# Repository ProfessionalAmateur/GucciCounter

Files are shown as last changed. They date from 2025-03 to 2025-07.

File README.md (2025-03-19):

# Gucci Counter

## Parts to buy:
1. **TinyScreen+** (https://tinycircuits.com/products/tinyscreenplus)
2. **TinyAccelerometer** (https://tinycircuits.com/products/accelerometer-tinyshield)
3. **Battery** (https://tinycircuits.com/products/lithium-ion-polymer-battery-3-7v-290mah)
4. **M3 bolt** (35mm)
5. **M3 Locking Nylon Nut**  
6. **Tactical paper clip** To press the buttons on the screen

## Parts to 3D print:  

1. **Main housing** https://github.com/ProfessionalAmateur/GucciCounter/blob/master/TinyScreenMainHousingPicatinny.stl  
2. **Picatinny small arm:** https://github.com/ProfessionalAmateur/GucciCounter/blob/master/MainHousingArmPicatinny.stl  
3. **Back Cover:** https://github.com/ProfessionalAmateur/GucciCounter/blob/master/TinyScreenBackPlate.stl  
(Please rotate objects as needed with your slicer for best printing quality)  

Once printed I drill out the bolt holes because the original design wanted something smaller, but I think an M3 bolt is better/best for a picatinny rail.

**Code to download:**  
https://github.com/ProfessionalAmateur/GucciCounter

**Assembly:** The accelerometer clips right into the back of the TinyScreen+ as well as the battery.
Once assembled insert the screen, accelerometer and battery into the 3d printed housing and affix the back cover.  
  
Connect the screen to your computer via a micro USB cable (this cable also charges the battery).
Open up Arduino IDE and upload the code program downloaded in step 3. (You may need to research how to connect your arduino to your PC but it is really straight forward.)

After the battery is fully charged and program uploaded to the device attached the unit to the picatinny rail if your desire.

## Button functions:

**Top Left:** Resets to 30 round magazine and will decrement with each round.  
**Top Right:** : Resets to 20 round magazine and will decrement with each round.  
**Bottom Left:** Resets to 0 and will increment with each round.  
**Bottom Right:** Resets to 0 and will increment with each round.  

## Constants/Variables
There are a couple of constant variables in the program you can feel free to change:  
  
**BIG_MAG:** I keep mine at 30 but if folks have 50 or 100 or 256 round magazine you will want to change this number.

**LITTLE_MAG:** Same as above if you have  10, 5 or 1 round magazine you will want to change this number.   

**Z_AXIS_GFORCE_THRESHOLD:** This value is a little tricky.  For my AR (which has almost no recoild because I built it myself and did it perfectly) a shot is just over 2g's but every gun is different, so if a shot is not registering I would lower this number.  If its registering too many, for some reason, raise it up.  This is where all the research and development dollars go into tuning.  

**X_AXIS_GFORCE_THRESHOLD & Y_AXIS_GFORCE_THRESHOLD:** These settings are to help prevent accidental 'round counts' when the firearm is placed down (On the stock or barrel) and registers an high G force across two or three directions.  All shots will come from the z-axis, but if you place your gun down or drop it in a corner it might register acceleration across all 3 axis'.  There is probably a better way to do this but alas, this is how I did it.

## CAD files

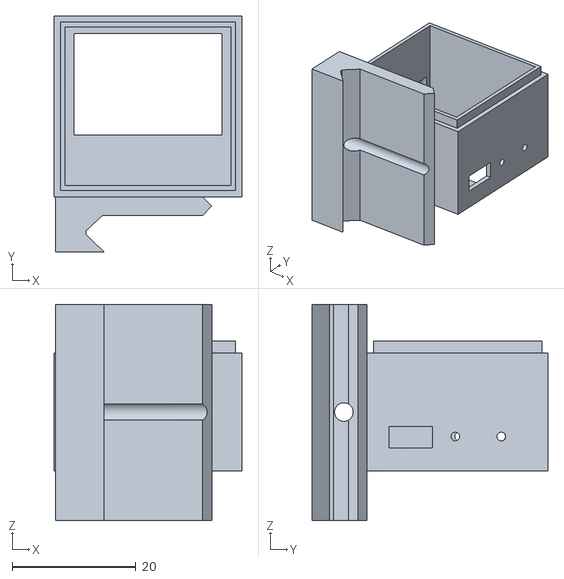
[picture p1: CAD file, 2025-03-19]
TinyScreenMainHousingPicatinny.stl
30.4 x 38.2 x 35.0

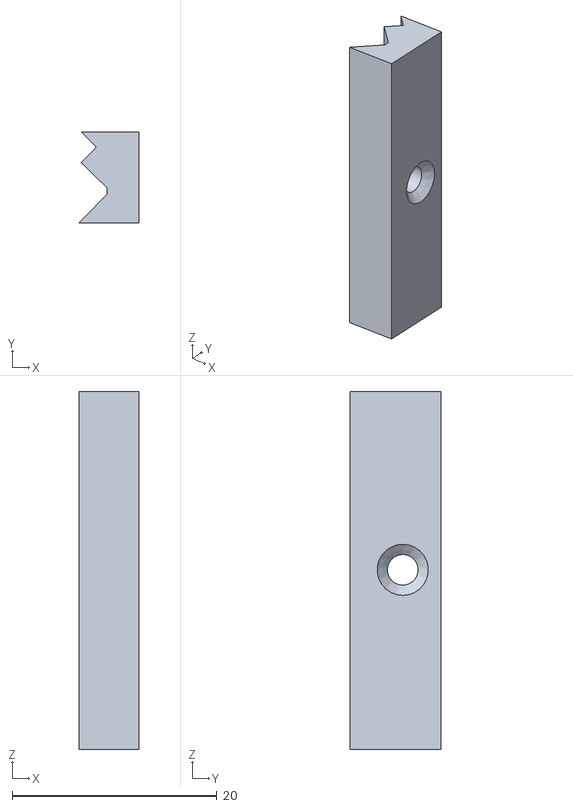
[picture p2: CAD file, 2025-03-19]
MainHousingArmPicatinny.stl
5.88 x 8.91 x 35.0

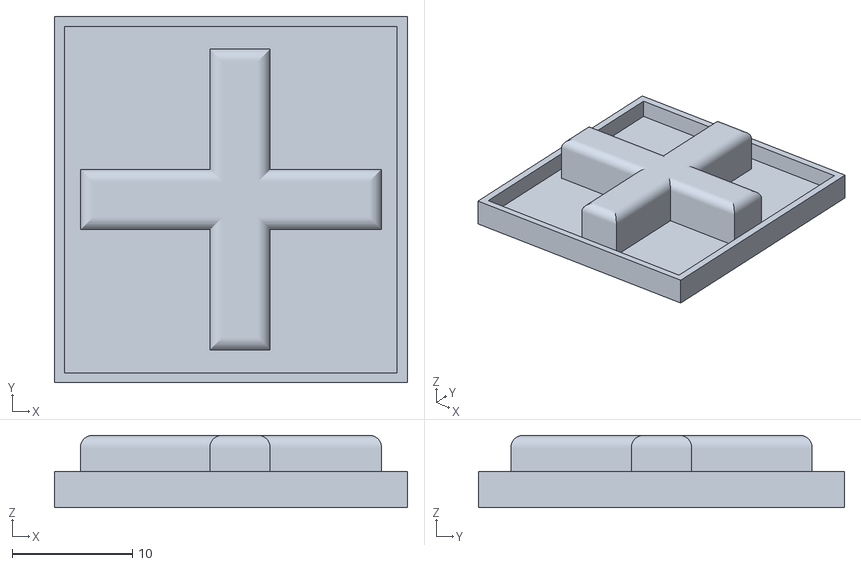
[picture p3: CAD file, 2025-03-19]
TinyScreenBackPlate.stl
29.3 x 30.4 x 6.00

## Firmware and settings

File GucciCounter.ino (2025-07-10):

#include <Wire.h>
#include <SPI.h>
#include <TinyScreen.h>
#include "BMA250.h"
#include <cmath>

// Library must be passed the board type
// TinyScreenPlus for TinyScreen+
TinyScreen display = TinyScreen(TinyScreenPlus);
int ctr = 0;
BMA250 accel_sensor;
int16_t x, y, z;
float max_xg = 0;
float max_yg = 0;
float max_zg = 0;
bool increment = true;
const int BIG_MAG = 30;
const int LITTLE_MAG = 20;
const float Z_AXIS_GFORCE_THRESHOLD = 0.50; // This is pretty low, but when the last round is fired and the bolt locks back the counter wasnt not registering.
const float X_AXIS_GFORCE_THRESHOLD = 0.93;
const float Y_AXIS_GFORCE_THRESHOLD = 0.75;

// I need to play with this number as for some shots met all the requirements but did not register.
const int COUNT_DELAY = 50;

// Define the update interval (in milliseconds)
#define UPDATE_INTERVAL 16 // 500 ms = 0.5 seconds

void setup(void)
{
  display.begin();
  // Sets main current level, valid levels are 0-15
  display.setBrightness(15);
  flipDisplay(true);
  Wire.begin();
  // Set up the BMA250 acccelerometer sensor
  accel_sensor.begin(BMA250_range_16g, BMA250_update_time_16ms);
}

void loop()
{
  // If the BMA250 is not found, nor connected correctly, these values will be produced
  // by the sensor
  if (x == -1 && y == -1 && z == -1)
  {
    // Print error message to Serial Monitor
    // Should probably error some how, some way....
  }
  else
  { // if we have correct sensor readings:
    writeAccel();
  }
  buttonLoop();
  // delay(UPDATE_INTERVAL);
}

void flipDisplay(bool flipFlag)
{
  display.setFlip(flipFlag);
}

void writeAccel()
{
  if (!increment && ctr == 0)
  {
    writeGameOver();
    return;
  }

  display.clearScreen();
  display.drawRect(0, 0, 96, 64, TSRectangleNoFill, 255, 0, 0);

  // Fetch accelerometer data and convert as needed.
  accel_sensor.read();
  float scaleFactor = 32.0;
  x = accel_sensor.X;
  y = accel_sensor.Y;
  z = accel_sensor.Z;
  // Optionally, convert to m/s²
  float x_g = (x / scaleFactor);
  float y_g = (y / scaleFactor);
  float z_g = (z / scaleFactor);
  float x_ms2 = (x / scaleFactor) * 9.81;
  float y_ms2 = (y / scaleFactor) * 9.81;
  float z_ms2 = (z / scaleFactor) * 9.81;

  // Counter Logic
  // if the current z accel reading is +/- 2g increment counter
  if ((z_g > Z_AXIS_GFORCE_THRESHOLD) && (fabs(x_g) >= X_AXIS_GFORCE_THRESHOLD) && (fabs(y_g) <= Y_AXIS_GFORCE_THRESHOLD))
  {
    if (increment)
    {
      ctr++;
    }
    else
    {
      ctr--;
    }
    delay(COUNT_DELAY); // I hope this is enough to capture the full round cycle but prevents double round counts
  }

  //==========================================================
  // Used for debugging purposes.
  if ((accel_sensor.X / scaleFactor) > max_xg)
  {
    max_xg = accel_sensor.X / scaleFactor;
  }
  if ((accel_sensor.Y / scaleFactor) > max_yg)
  {
    max_yg = accel_sensor.Y / scaleFactor;
  }
  if ((accel_sensor.Z / scaleFactor) > max_zg)
  {
    max_zg = accel_sensor.Z / scaleFactor;
  }
  //==========================================================

  displayData();

  // COMMENT OUT IF NOT DEBUGGING
  displayDebug(x_g, y_g, max_zg);
}

void displayData()
{
  display.setFont(liberationSans_22ptFontInfo);
  char txtCount[10];
  itoa(ctr, txtCount, 10);
  int16_t x = (48 - (display.getPrintWidth(txtCount) / 2));
  int16_t y = (32 - (display.getFontHeight() / 2));
  display.setCursor(x, y);
  display.fontColor(TS_8b_Red, TS_8b_Black);
  display.print(txtCount);
}

void displayDebug(float x_g, float y_g, float max_zg)
{
  //==========================================================
  // Used for debugging purposes.
  display.setFont(liberationSansNarrow_8ptFontInfo);
  display.fontColor(TS_8b_Red, TS_8b_Black);
  display.setCursor(65, 5);
  display.print("X" + String(x_g));
  display.setCursor(65, 15);
  display.print("Y" + String(y_g));
  display.setCursor(5, 45);
  display.print("Z(m): " + String(max_zg));
  // delay(UPDATE_INTERVAL);
  //==========================================================
}

void buttonLoop()
{
  // 30 Round mag, decrement
  if (display.getButtons((TSButtonUpperLeft)))
  {
    clearMax();
    ctr = BIG_MAG;
    increment = false;
  }

  // 20 Round mag, decrement
  if (display.getButtons((TSButtonUpperRight)))
  {
    clearMax();
    ctr = LITTLE_MAG;
    increment = false;
  }

  // Simple counter, increment
  if (display.getButtons((TSButtonLowerLeft)))
  {
    clearMax();
    ctr = 0;
    increment = true;
  }

  // reset max z axis g
  if (display.getButtons(TSButtonLowerRight))
  {
    clearMax();
    ctr = 0;
    increment = true;
  }
}

void clearMax()
{
  max_xg = 0;
  max_yg = 0;
  max_zg = 0;
}

void writeGameOver()
{
  char sInsert[7] = "Insert";
  char sCoin[7] = "Coin";

  display.drawRect(0, 0, 96, 64, TSRectangleFilled, 255, 0, 0);
  // setFont sets a font info header from font.h
  // information for generating new fonts is included in font.h
  display.setFont(liberationSans_16ptFontInfo);
  display.fontColor(TS_8b_Red, TS_8b_Black);

  int insWidth = display.getPrintWidth(sInsert);
  int coinWidth = display.getPrintWidth(sCoin);

  // fontColor(text color, background color);//sets text and background color
  display.fontColor(TS_8b_Black, TS_8b_Red);
  display.setCursor(38 - (insWidth / 4), 10);
  display.print(sInsert);
  display.setCursor(38 - (coinWidth / 4), 30);
  display.print(sCoin);
  delay(1000);
}

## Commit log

2025-03-19 Changed Y_AXIS_GFORCE_THRESHOLD to 0.65
2025-03-29 Changed X axis threshold, changed delay interval, lowered z axis threshold to handle subs, moved debugging to its old function. drank a beer. Range time
2025-04-01 Changed X axis check, and Z-axis to trigger subsonic rounds
2025-04-20 Set z axis to only register positive g force values to prevent from housing a round when you send the bolt forward on a reload. Clean up debugging and reset function.
    [GucciCounter.ino]
2025-05-03 Readded update interval to prevent screen flicker
    [GucciCounter.ino]
2025-05-18 Shortened delay value as for some shots were not registering. Decreased z-threshold to count the last round when the bolt locks open.
    [GucciCounter.ino]
2025-07-10 Still tuning delay issues.
    [GucciCounter.ino]
